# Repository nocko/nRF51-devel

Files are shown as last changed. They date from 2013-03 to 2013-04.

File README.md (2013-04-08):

nRF51x22 Barebones Development Board
====================================

rendering of board front

Make your own! ($9 for 3 boards + ~$10/ea. in parts) 
----------------------------------------------------

 1. In a web browser: Browse to [oshpark.com](http://oshpark.com),
    select "Get Started Now", then "Select a file on your
    computer". Select gerbers/nRF51.zip from the repo. Fill out the
    name, contact and billing information.

 1. Order the parts. Current BoM Shopping Cart (for three boards) @
    Mouser:
    http://www.mouser.com/ProjectManager/ProjectDetail.aspx?AccessID=88e3ea2c37

 1. Practice your [reflow soldering
    technique](https://www.sparkfun.com/tutorials/59) while you wait
    for parts and boards to show up.

 1. Fun!

Make it better
--------------

If you've never used gEDA before, start with this simple
[tutorial](http://hobby-electrons.sourceforge.net/tutorials/gEDA/index.html). Once
you're familiar with the gschem and pcb UI feel free to clone the repo
in github with the [fork button](https://github.com/nocko/nRF-devel/fork)
or clone the repo using the CLI:

    git clone https://github.com/nocko/nRF51-devel

Interesting Files in the Repo
-----------------------------

* nRF51.sch:

	gschem schematic. Edit this file with *gschem* to add or
	remove components or change the way the components are
	connected.

* nRF51.pcb:
 
  	pcb layout. Edit with *pcb* to change the locations of the
	components on the board or to place new components added in
	gschem.

* attrib:

	template files for the fields that should appear in a bill of
	materials file generated by *gnetlist*

* project:

	gsch2pcb project file. Setup options to import tdcs.sch into
	board.pcb. Options like path to pcb footprints, names of
	schematics to process, and output name.

* gafrc:
 
       Options for gschem. Primarily the location of local schematic
       symbols

* gerber/*:
	
	Gerber files generated from the *.pcb files. generate-gerbers
	builds the gerbers and creates a zipfile(s) that can be sent
	to [OSH Park](http://oshpark.com/) without modification.

* bom.txt:

	Bill of Materials, the components you need to buy to populate
	the board. Eventually this will auto generate via gnetlist,
	but for now the digikey part numbers are added manually.

General Workflow
----------------

1. Add new components or change the circuit diagram in nRF51.sch using
*gschem*.

1. Run: ```gsch2pcb project```

1. Follow the instructions provided by gsch2pcb to insert the new
components.

1. Adjust the pcb layout using *pcb* and save file

1. Make gerbers/oshpark zip files: ```cd gerbers; ./generate-gerbers.sh```

1. Recreate the BoM: ```gnetlist -g bom -o bom.txt <project>.sch```

License
-------

All files are licensed [CC-BY
3.0](http://creativecommons.org/licenses/by/3.0/) unless otherwise marked. Full text of the
CC license is available in LICENSE.txt

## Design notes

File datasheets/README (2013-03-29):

This folder holds the datasheets for the components specified in the BoM

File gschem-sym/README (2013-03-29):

This folder holds custom gschem parts for schematics

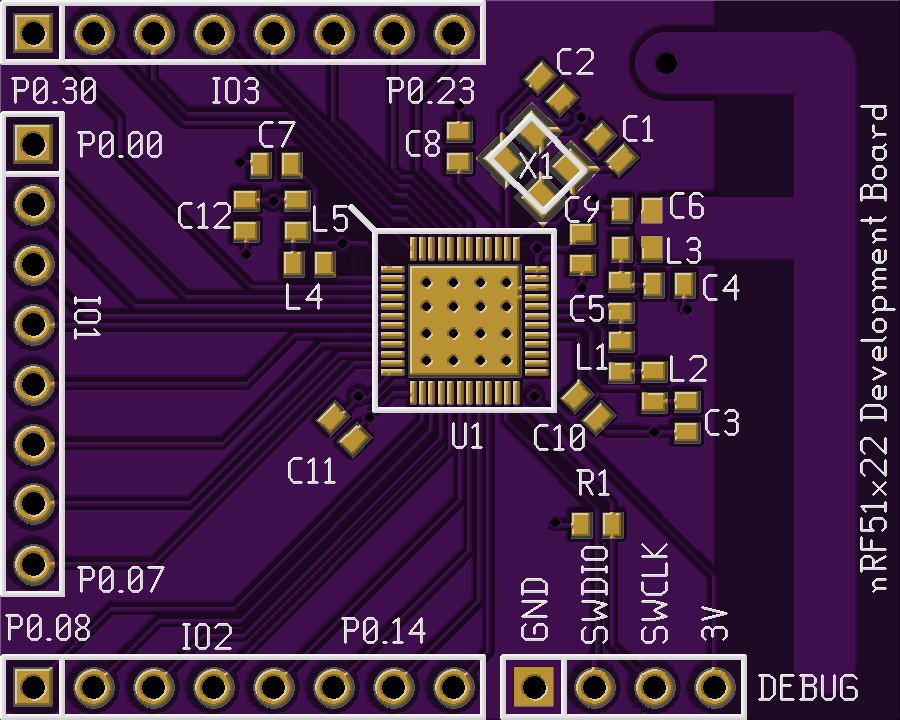
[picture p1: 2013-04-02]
nRF51-top.png

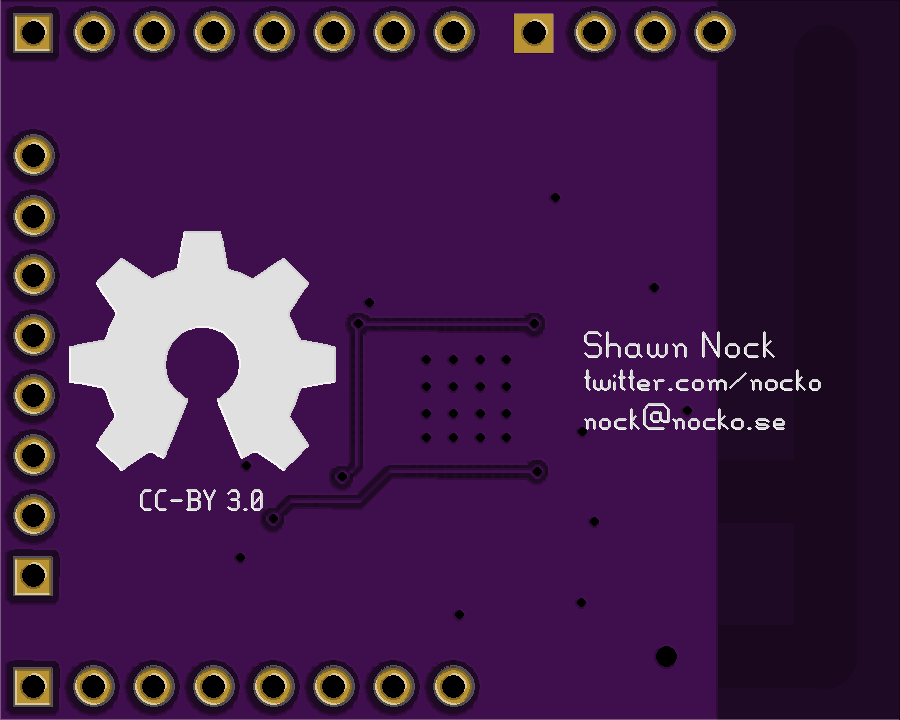
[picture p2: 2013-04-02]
nRF51-bottom.png

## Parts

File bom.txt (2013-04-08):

refdes:device:value:footprint:mouser:qty
U1:nRF51x22:unknown:QFN48_6_EP:949-NRF51822-QFAB-R7:1
C1,C2:CAPACITOR:12pF:0603:VJ0603A120FXACW1BC:2
L5:INDUCTOR:15nH:0603:652-CI160808-15NJ:1
L4:INDUCTOR:10uH:0603:810-MLZ1608E100M:1
C7:CAPACITOR:4.7uF:0603:603-CC603KRX5R6BB475:1
C11,C8:CAPACITOR:100nF:0603:77-VJ0603Y104KXJCBC:2
C9:CAPACITOR:1nF:0603:581-06033C102JAT4A:1
C10:CAPACITOR:47nF:0603:810-C1608X7R1H473K:1
L1:INDUCTOR:4.7nH:0603:652-CI160808-4N7D:1
L2:INDUCTOR:10nH:0603:652-CI160808-10NJ:1
C3:CAPACITOR:2.2nF:0603:77-VJ1206Y222KXACBC:1
C5:CAPACITOR:2.2pF:0603:77-VJ0603A2R2BXACBC:1
C4:CAPACITOR:1pF:0603:77-VJ0603A1R0BXACBC:1
C6:CAPACITOR:1.5pF:0603:77-VJ0603A1R5BXACBC:1
L3:INDUCTOR:3.3nH:0603:652-CI160808-3N3D:1
R1:RESISTOR:12K:0603:301-12K-RC:1
DEBUG:CONNECTOR_4:unknown:JUMPER4:517-974-01-04-RK:1
C12:CAPACITOR:1uF:0603:810-C1608X7R1A105K:1
IO1,IO2,IO3:CONNECTOR_8:unknown:JUMPER8:517-929850-01-08-RB:3
X1:CRYSTAL:unknown:CRYSTAL 3225:581-CX3225SB16D0FLJ:1

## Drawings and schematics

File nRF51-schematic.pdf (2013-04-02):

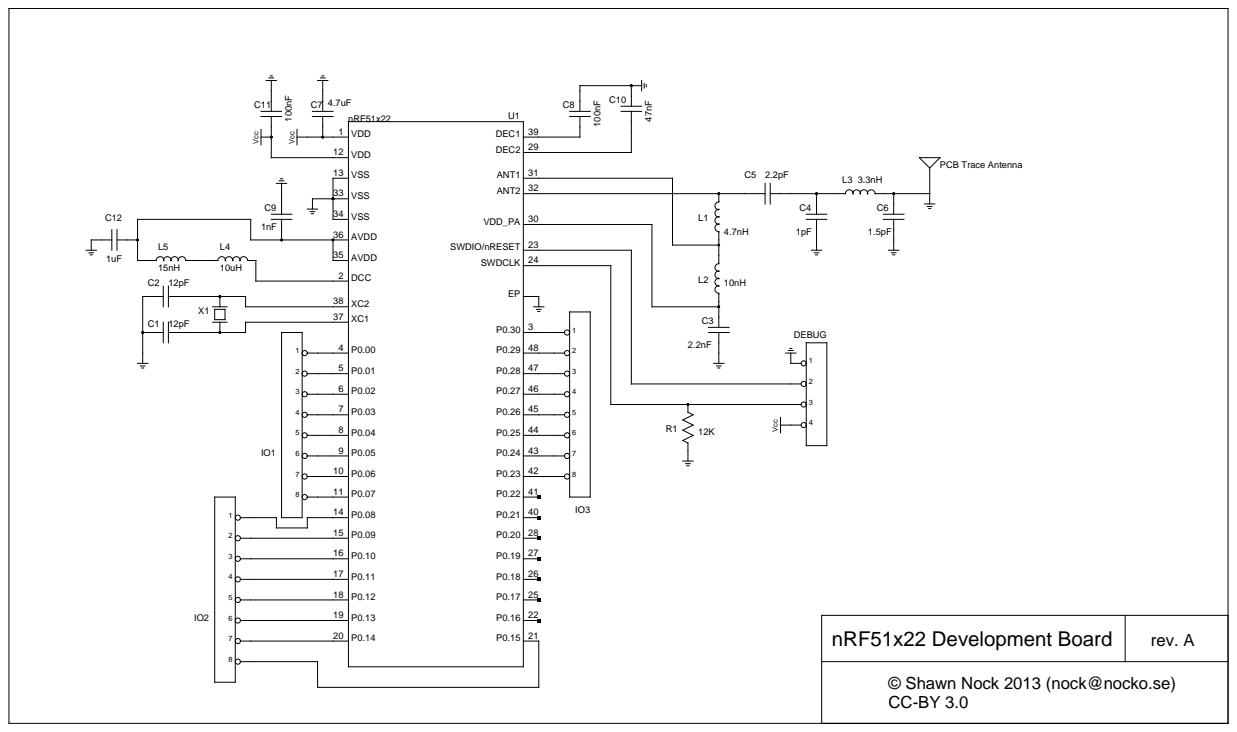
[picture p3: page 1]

© Shawn Nock 2013 (nock@nocko.se)

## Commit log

2013-03-29 Adds dummy README files to track the empty directories
2013-03-31 Adds symbol for SoC
    [nRF51.sch]
2013-04-01 Adds passives and first try board layout
    [nRF51.sch]
2013-04-01 Adds F style trace antenna (50ohm feedline + ~1/4 wavelength)
2013-04-01 Makes generate-gerbers.sh executable
2013-04-01 Adds pcb temporary files to .gitignore
2013-04-01 First pass gerbers, no routing of SoC io pins
    [nRF51.bottom.gbr, nRF51.bottommask.gbr, nRF51.fab.gbr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]
2013-04-01 Adds net to antenna to aid adding an SMA jack in the future
    [nRF51.sch]
2013-04-01 Adds PDF preview of schematic
2013-04-01 Adds top plane and fixes mask on SoC
    [nRF51.sch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]
2013-04-01 Cleanup and Branding
    [nRF51.bottom.gbr, nRF51.bottommask.gbr, nRF51.bottomsilk.gbr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]
2013-04-01 Pretties up the schematic
    [nRF51.sch]
2013-04-02 Adds explicit ground connections for EP and Antenna
    [nRF51.sch]
2013-04-02 Updates schematic pdf preview with explicit EP connection
2013-04-02 Switches to chip crystal, improves power decoupling, adds mouser part numbers
    [nRF51.sch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]
2013-04-02 Subs out backordered parts. Links mouser shared cart to README
    [nRF51.sch]
2013-04-08 Change C9 to a part on which mouser doesn't have minimum quantity
    [nRF51.sch]
